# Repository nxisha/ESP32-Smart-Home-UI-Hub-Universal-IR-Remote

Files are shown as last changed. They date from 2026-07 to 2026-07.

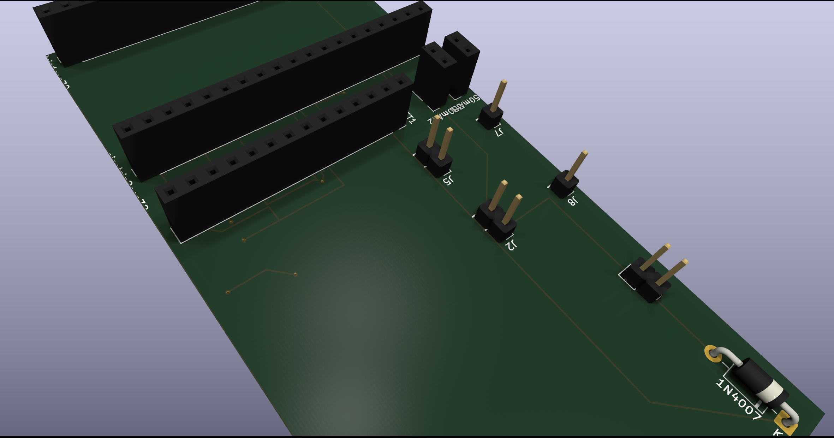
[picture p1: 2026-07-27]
PCBlayout3.png

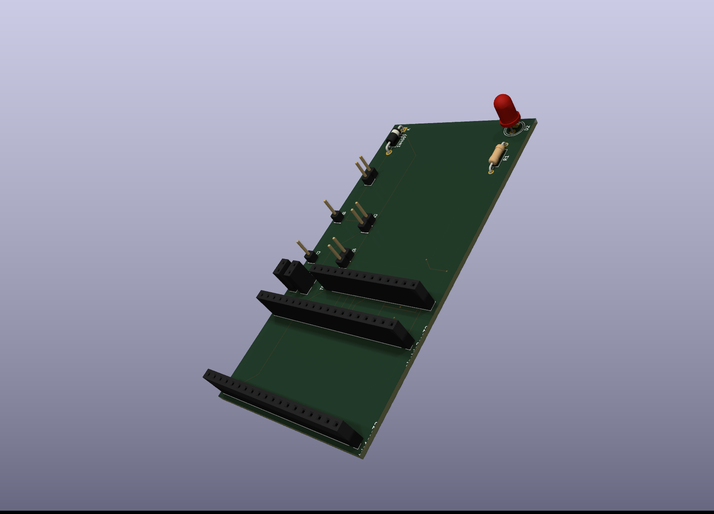
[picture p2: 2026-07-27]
PCBlayout.png

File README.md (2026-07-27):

ESP32 Smart Home UI Hub & Universal IR/BLE Remote

A physical demonstration of the Smart Hub navigating Fire TV via BLE and operating Voltas/Hitachi HVAC units via synthesized IR pulses.

Architecture Overview

A centralized smart home control terminal built around an ESP32-WROOM-32 and a 2.8-inch TFT SPI touch display. This hub unifies control over disparate home appliances by bridging Infrared (IR), Bluetooth Low Energy (BLE), and Wi-Fi protocols into a single concurrent interface.

It actively operates a dual-role BLE architecture—acting as a Server (HID Keyboard) for streaming devices, and a Client for reverse-engineered smart lighting control, bypassing proprietary commercial hubs.

Hardware Stack

MCU: ESP32-WROOM-32 Development Board (Tensilica Xtensa Dual-Core 32-bit LX6)

Display Interface: 2.8" TFT LCD Touch Screen (ILI9341 Driver, XPT2046 Touch Controller)

IR Subsystem: 940nm Infrared LED with current-limiting 220Ω series resistor

Power Architecture:

2x 350mAh 3.7V LiPo Batteries (Parallel configuration for 700mAh capacity)

TP4056 Lithium Battery Charger IC (1A regulated input)

1N4007 Diode (Voltage step-down regulation)

GPIO Pinout & Wiring

Peripheral / Component

ESP32 GPIO

Notes / Alternate Function

TFT_MOSI

GPIO 23

VSPI MOSI

TFT_MISO

GPIO 19

VSPI MISO

TFT_SCLK

GPIO 18

VSPI CLK

TFT_CS

GPIO 15

Chip Select

TFT_DC

GPIO 2

Data/Command

TFT_RST

GPIO 4

Hardware Reset

TOUCH_CS

GPIO 21

Touch Controller CS

IR_TX

GPIO 12

PWM Carrier Generation (38kHz)

Power Subsystem & Diode Regulation

Due to the high transient current spikes required by active IR transmission and the TFT backlight, power is handled via a direct parallel battery array, intentionally bypassing switching buck converters to maximize discharge utilization:

Cell Configuration: Wired in parallel yielding 3.7V nominal @ 700mAh.

Voltage Stepping: Battery positive is routed through a physical SPST switch and into the Anode of a 1N4007 diode.

Logic Leveling: The Cathode drops the 4.2V peak charge by ~0.7V (Forward Voltage Drop), delivering a safe ~3.5V to the ESP32 3V3 pin and TFT VIN, operating safely within absolute maximum ratings without converter switching noise.

Proof of Hardware

View KiCad Schematic / Wiring Diagram

View Logic Analyzer Trace (38kHz IR Carrier)

Build & Flash Instructions

1. IDE Configuration

Environment: Arduino IDE 2.x or PlatformIO

Board: ESP32 Dev Module

Partition Scheme: Huge APP (3MB No OTA/1MB SPIFFS) (Required due to BLE + TFT library overhead).

2. Dependencies

TFT_eSPI by Bodmer (Must configure User_Setup.h for ILI9341 and assigned VSPI pins).

IRremoteESP8266 by crankyoldgit.

BleKeyboard by T-vK.

3. Syska BLE Configuration

To interface directly with the Syska Smart LED without the manufacturer app, configure the target MAC address in ESP32_Smart_Remote.ino:

// Update to target Syska Bulb MAC Address
BLEAddress bulbAddress("11:22:33:44:55:66"); 

4. Compilation

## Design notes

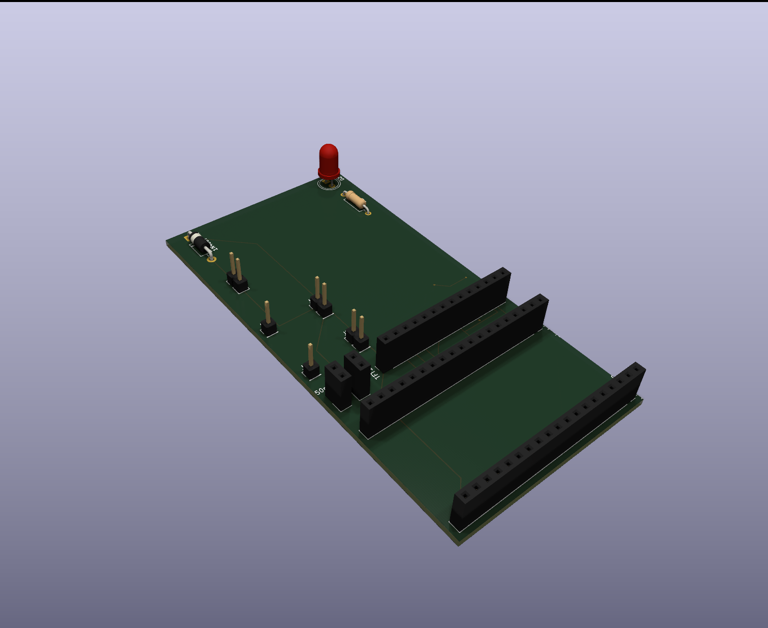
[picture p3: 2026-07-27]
PCBlayout2.png

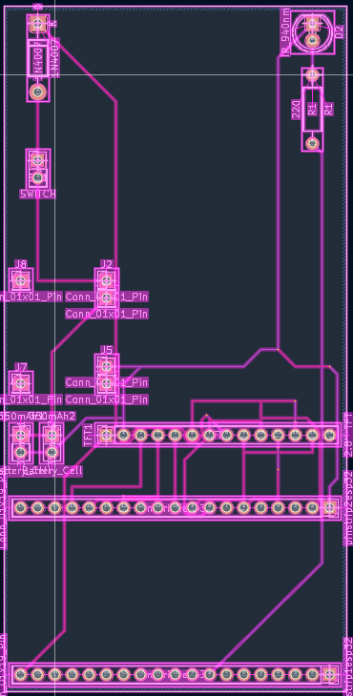
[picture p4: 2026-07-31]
Screenshot 2026-07-27 at 20.01.56.png

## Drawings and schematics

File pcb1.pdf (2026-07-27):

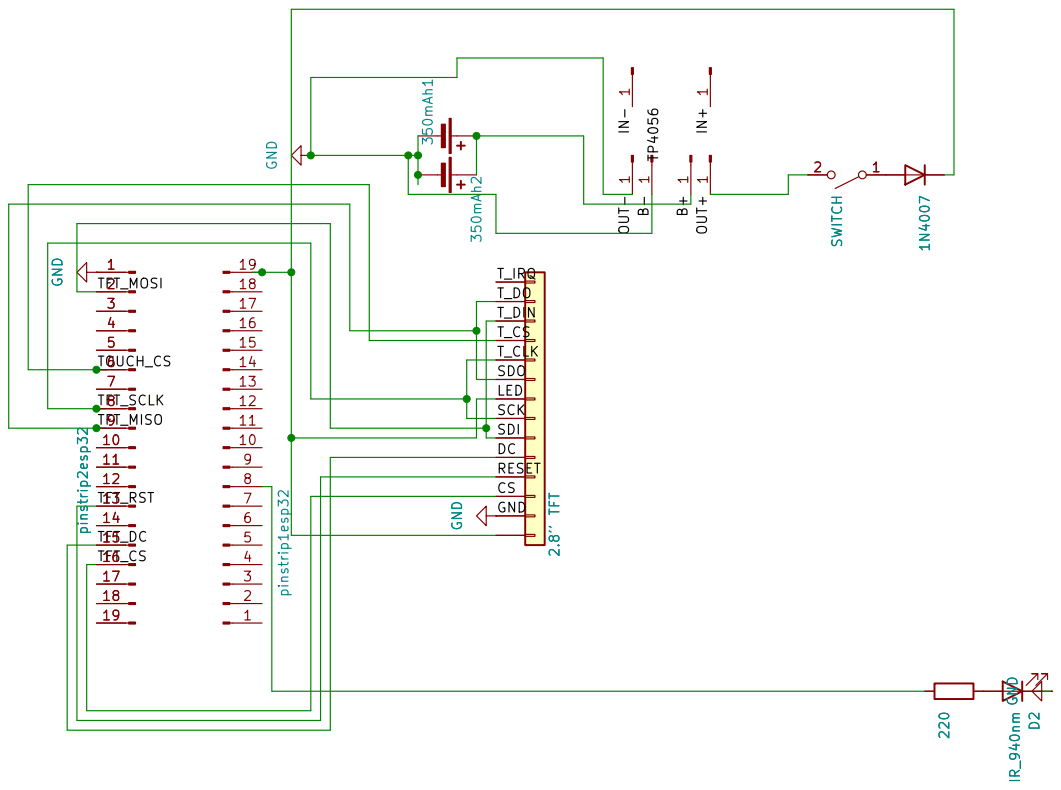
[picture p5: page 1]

Size: A4 | Rev:
KiCad E.D.A. 10.0.3 | Id: 1/1

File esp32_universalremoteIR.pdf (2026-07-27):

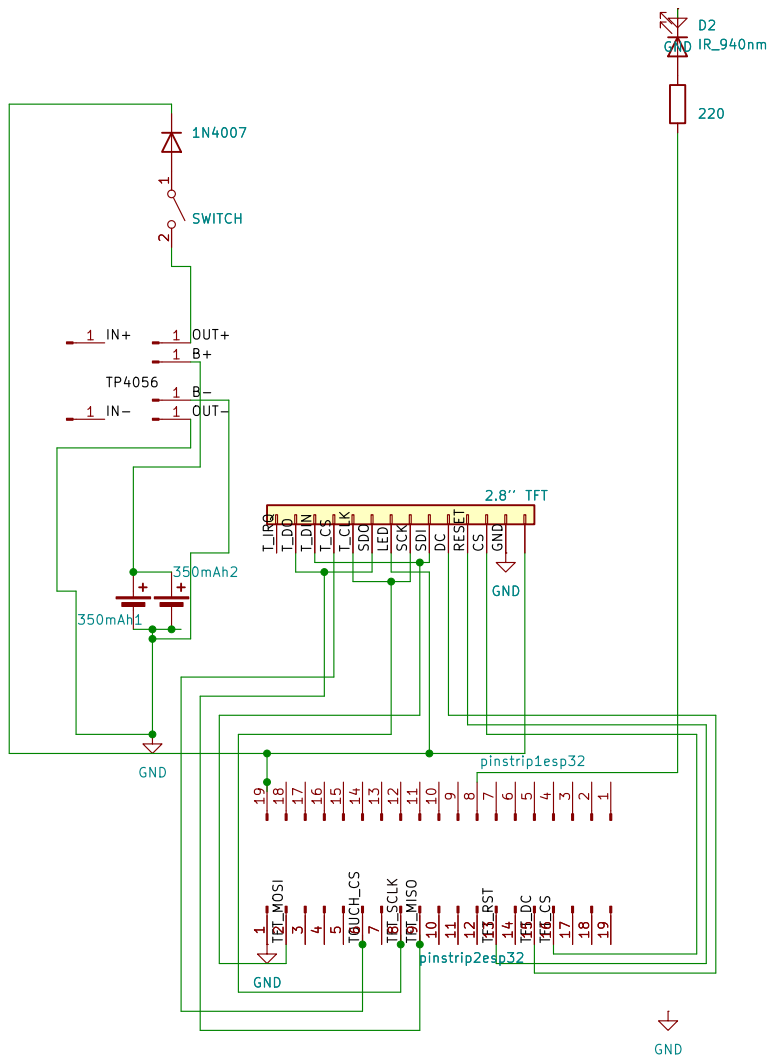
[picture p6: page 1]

Size: A4 | Rev:
KiCad E.D.A. 10.0.3 | Id: 1/1

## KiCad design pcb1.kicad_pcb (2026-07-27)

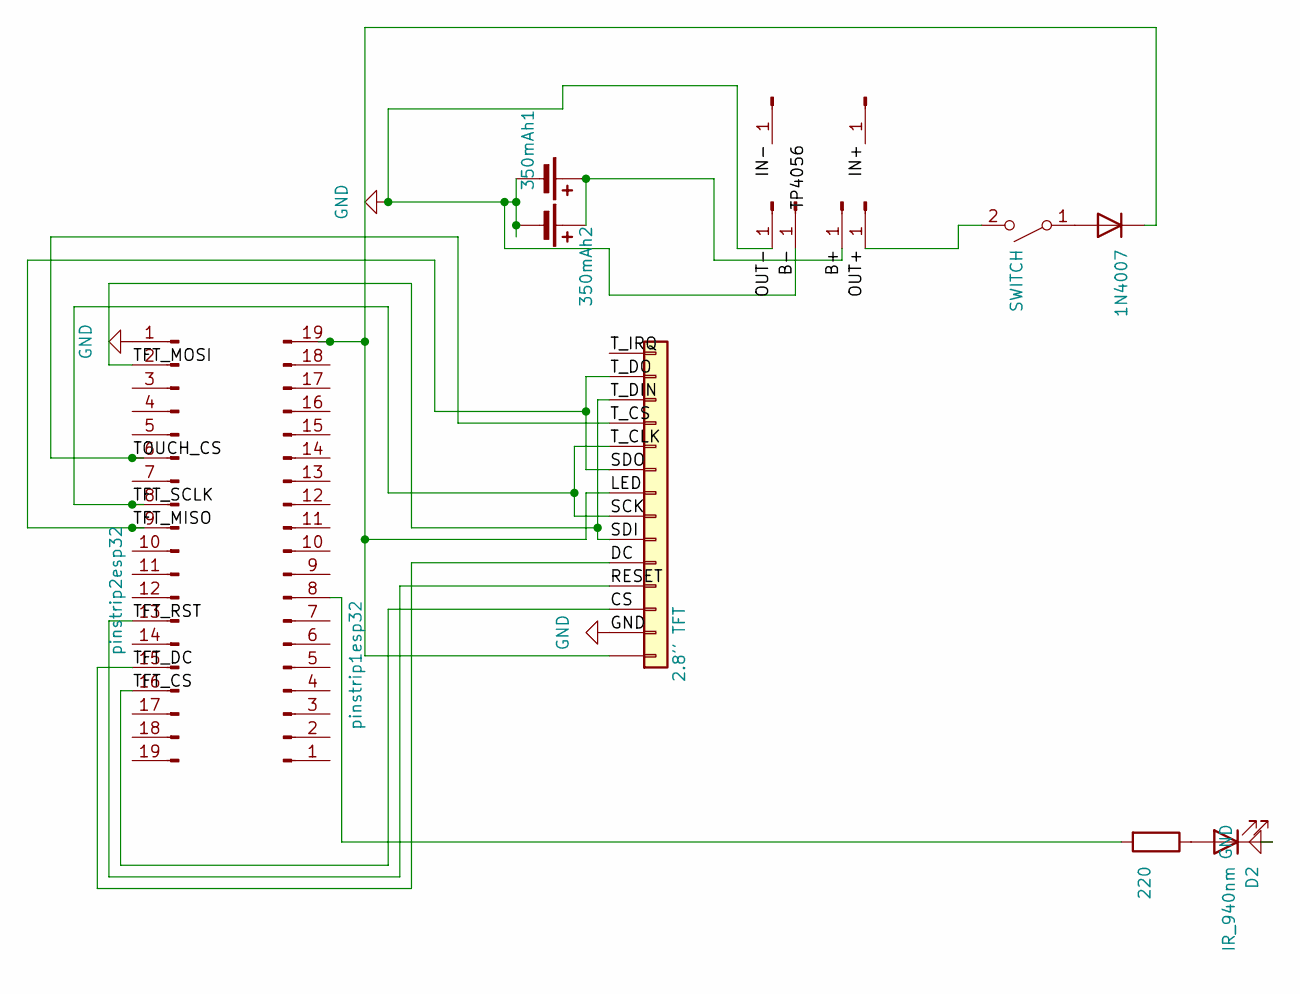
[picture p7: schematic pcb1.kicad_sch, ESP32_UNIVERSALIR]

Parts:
1N4007: D; D_DO-41_SOD81_P10.16mm_Horizontal
350mAh1, 350mAh2: Battery_Cell; PinSocket_1x02_P2.54mm_Vertical
D2: IR_940nm; LED_D5.0mm
J2, J4, J5, J6, J7, J8: Conn_01x01_Pin; PinHeader_1x01_P2.54mm_Vertical
R1: 220; R_Axial_DIN0207_L6.3mm_D2.5mm_P10.16mm_Horizontal
SW1: SWITCH; PinHeader_1x02_P2.54mm_Vertical
TFT1: 2.8'' TFT; PinSocket_1x14_P2.54mm_Vertical
pinstrip1esp32, pinstrip2esp32: Conn_01x19_Pin; PinSocket_1x19_P2.54mm_Vertical

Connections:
/B+: 350mAh1.1 (+), 350mAh2.1 (+), J4.1 (Pin_1_1)
/CS: TFT1.3, pinstrip2esp32.16
/DC: TFT1.5, pinstrip2esp32.15
/IN+: J8.1 (Pin_1_1)
/IN-: J7.1 (Pin_1_1)
/LED: 1N4007.1 (K), TFT1.1, TFT1.8, pinstrip1esp32.19
/OUT+: J2.1 (Pin_1_1), SW1.2 (B)
/RESET: TFT1.4, pinstrip2esp32.13
/SCK: TFT1.7, TFT1.10, pinstrip2esp32.8
/SDI: TFT1.6, TFT1.12, pinstrip2esp32.2
/SDO: TFT1.9, TFT1.13, pinstrip2esp32.9
/TOUCH_CS: TFT1.11, pinstrip2esp32.6
/T_IRQ: TFT1.14
GND: 350mAh1.2 (-), 350mAh2.2 (-), D2.1 (K), J5.1 (Pin_1_1), J6.1 (Pin_1_1), TFT1.2, pinstrip2esp32.1
unnamed: 1N4007.2 (A), SW1.1 (A)
unnamed: D2.2 (A), R1.1
unnamed: R1.2, pinstrip1esp32.8

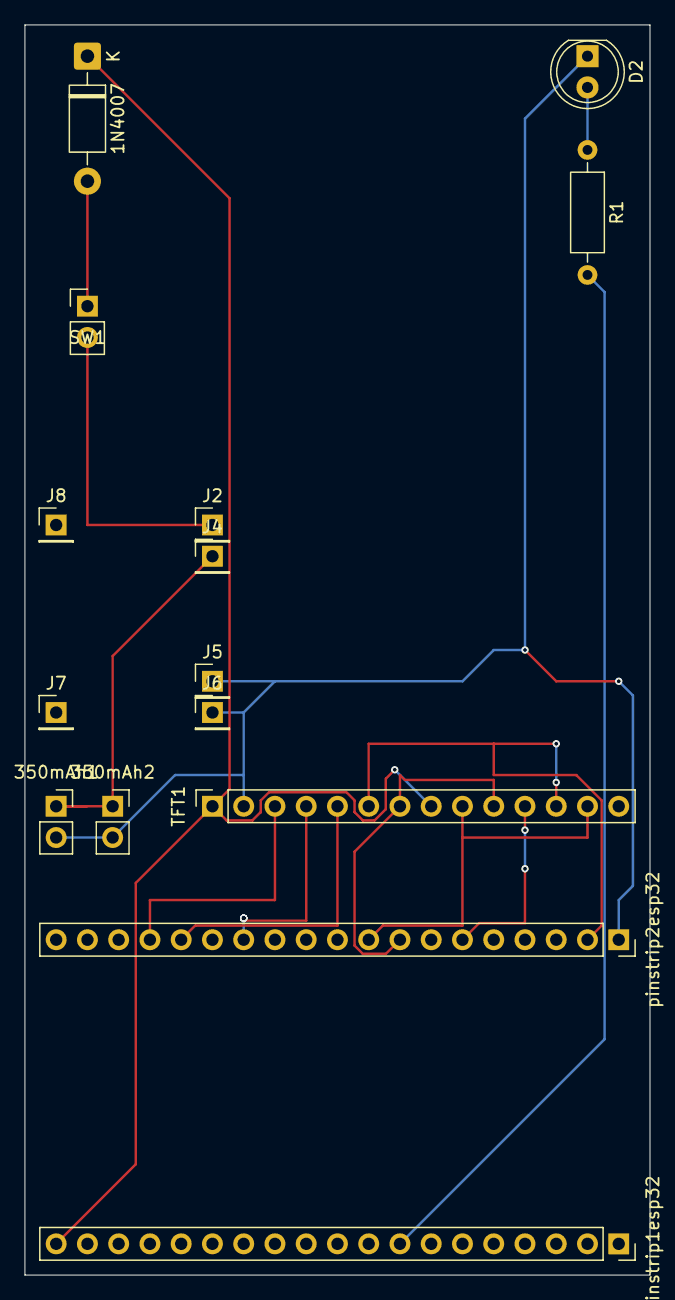
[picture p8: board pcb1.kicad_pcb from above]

Board: 2 copper layers, 50.8 x 101.6 mm, 15 parts (0 on the bottom side), 14 nets.

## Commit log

2026-07-27 KiCad files uploaded
    [pcb1.kicad_pcb, pcb1.kicad_sch]
2026-07-27 Schematic for people who dont yet have KiCad
2026-07-27 updated schematic
2026-07-27 photos of the project including proposed PCB plan
2026-07-31 PCB diagram
